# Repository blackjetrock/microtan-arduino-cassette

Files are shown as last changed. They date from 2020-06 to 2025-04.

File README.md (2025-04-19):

# microtan-arduino-cassette
Arduino based cassette system for Microtan computer

Uses Arduino Mega or Uno, depending on how much memory you need. Uno has 2K RAM mega has 8K. You can't use all of it for a buffer to store cassette information.

The connections to the cassette interface are not the external ones that attach to a tape recorder. They are instead pins 11 and 12 of connector B1 on the TANEX. This is logic level and removes the need for amplifiers and so on. Ground is also needed on B1.

The code runs only in fast mode. The data read from the Microtan is dumped to a buffer that can then go to an SD card.

SD card read isn't working yet.

When using the SAVE command the code displays data as it is received. The serial port on the Arduino runs at 115200 and there's enough time to send the bytes out of the port as the data is received.

Commands

clear:    Clears the memory buffer ready for a new SAVE.

display:  Displays the current contents of the buffer

savefile: Saves the buffer to a file on the attached SD card. The filename used is the embedded name in the data. 
          Data is curently saved in ASCII hex but binary is probably better as it can be directly sent back to the Microtan.

send:     Sends the data buffer back to the Microtan. There's a spurious byte at the start of the buffer that isn't sent back.

There are other commands used in development, I need to remove those or at least tidy them up.

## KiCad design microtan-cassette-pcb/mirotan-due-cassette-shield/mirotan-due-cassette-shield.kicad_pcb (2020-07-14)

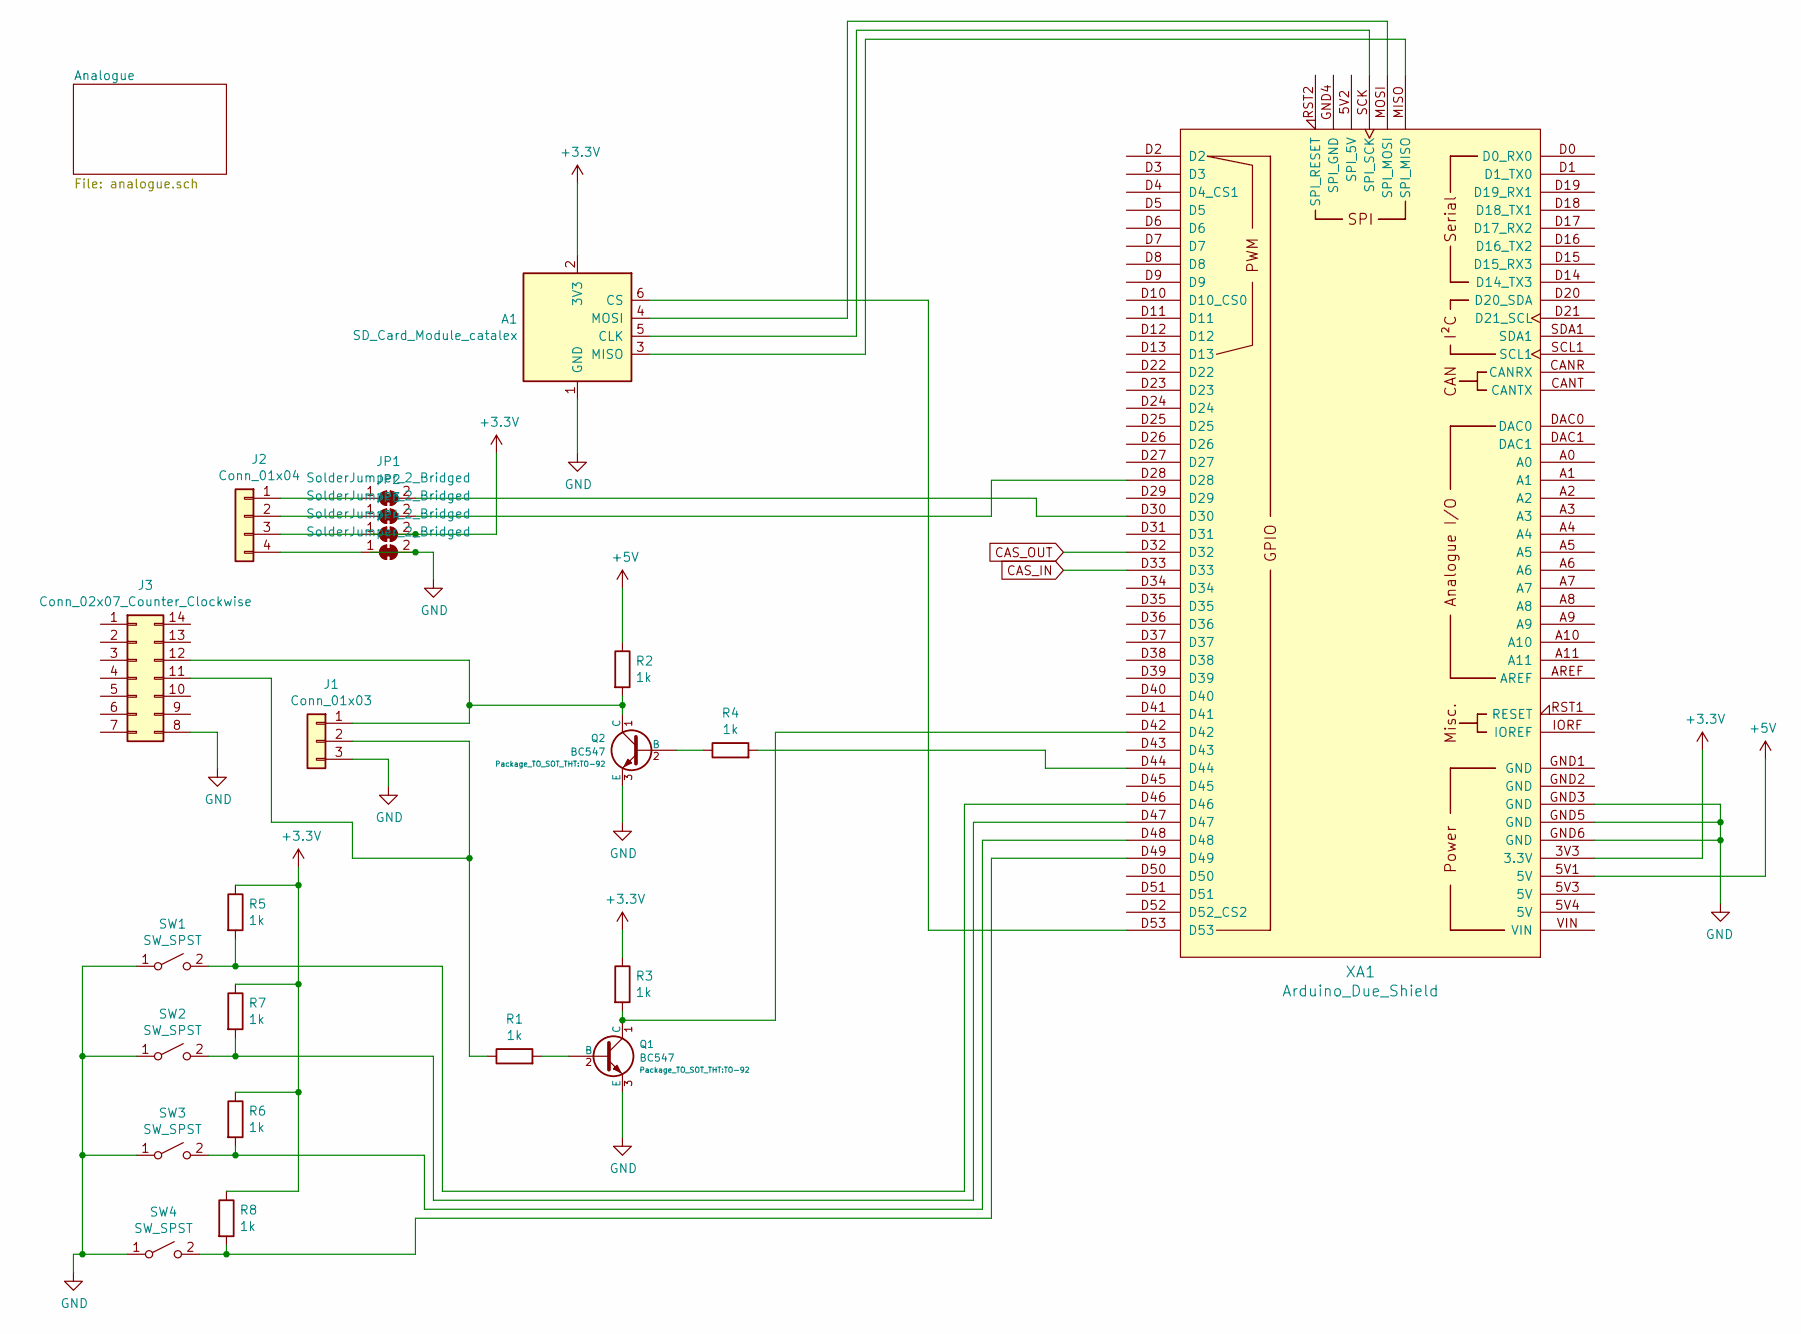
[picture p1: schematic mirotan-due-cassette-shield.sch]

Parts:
A1: SD_Card_Module_catalex; SD_Card_Module
J1: Conn_01x03; Molex_KK-254_AE-6410-03A_1x03_P2.54mm_Vertical
J2: Conn_01x04; Molex_KK-254_AE-6410-04A_1x04_P2.54mm_Vertical
J3: Conn_02x07_Counter_Clockwise; DIP-14_W7.62mm_Socket
JP1, JP2, JP3, JP4: SolderJumper_2_Bridged; SolderJumper-2_P1.3mm_Bridged2Bar_RoundedPad1.0x1.5mm
Q1, Q2: BC547; TO-92
R1, R2, R3, R4, R5, R6, R7, R8: 1k; R_Axial_DIN0207_L6.3mm_D2.5mm_P7.62mm_Horizontal
SW1, SW2, SW3, SW4: SW_SPST; SW_PUSH-12mm
XA1: Arduino_Due_Shield

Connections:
+3V3: A1.2 (3V3), JP3.2 (B), R3.1, R5.1, R6.1, R7.1, R8.1, XA1.3V3 (3.3V)
+5V: R2.1, XA1.5V1 (5V); also elsewhere on the board
CAS_IN: XA1.D33; also elsewhere on the board
CAS_OUT: XA1.D32; also elsewhere on the board
GND: A1.1 (GND), J1.3, J3.8, JP4.2 (B), Q1.3 (E), Q2.3 (E), SW1.1 (A), SW2.1 (A), SW3.1 (A), SW4.1 (A), XA1.GND3 (GND), XA1.GND5 (GND), XA1.GND6 (GND); also elsewhere on the board
unnamed: A1.3 (MISO), XA1.MISO (SPI_MISO)
unnamed: A1.4 (MOSI), XA1.MOSI (SPI_MOSI)
unnamed: A1.5 (CLK), XA1.SCK (SPI_SCK)
unnamed: A1.6 (CS), XA1.D53
unnamed: J1.1, J3.12, Q2.1 (C), R2.2
unnamed: J1.2, J3.11, R1.1
unnamed: J2.1, JP1.1 (A)
unnamed: J2.2, JP2.1 (A)
unnamed: J2.3, JP3.1 (A)
unnamed: J2.4, JP4.1 (A)
unnamed: JP1.2 (B), XA1.D30
unnamed: JP2.2 (B), XA1.D28
unnamed: Q1.1 (C), R3.2, XA1.D42
unnamed: Q1.2 (B), R1.2
unnamed: Q2.2 (B), R4.1
unnamed: R4.2, XA1.D44
unnamed: R5.2, SW1.2 (B), XA1.D46
unnamed: R6.2, SW3.2 (B), XA1.D48
unnamed: R7.2, SW2.2 (B), XA1.D47
unnamed: R8.2, SW4.2 (B), XA1.D49

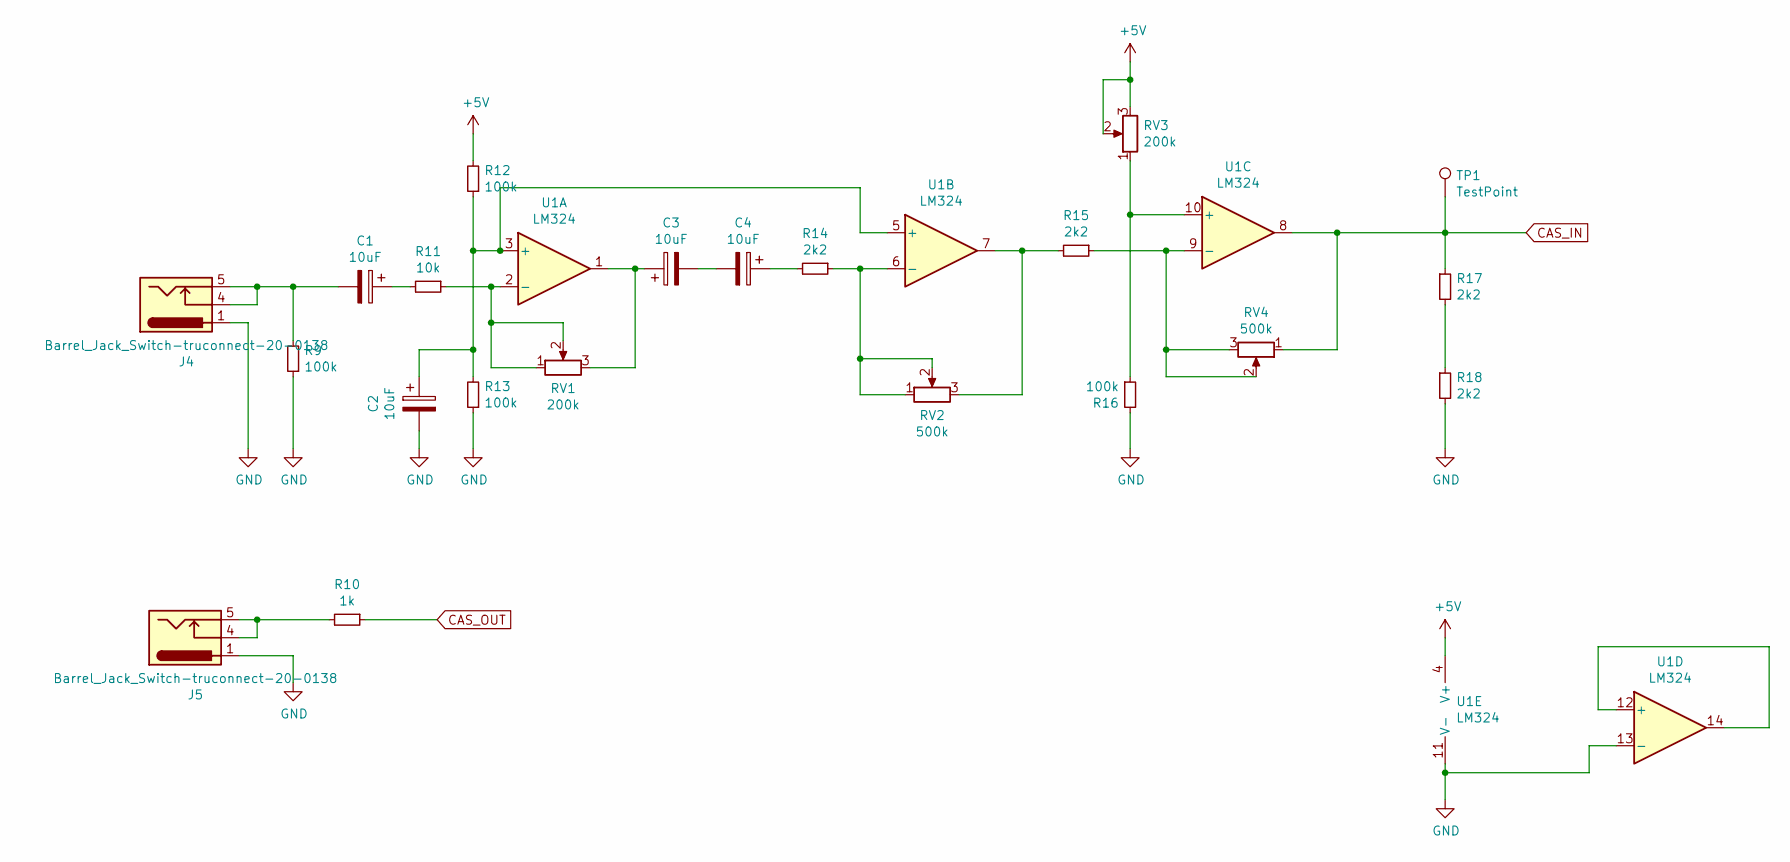
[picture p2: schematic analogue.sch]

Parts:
C1, C2, C3, C4: 10uF; CP_Radial_D5.0mm_P2.50mm
J4, J5: Barrel_Jack_Switch-truconnect-20-0138; truconnect-20-0138-mono-socket
R9, R12, R13, R16: 100k; R_Axial_DIN0207_L6.3mm_D2.5mm_P7.62mm_Horizontal
R10: 1k; R_Axial_DIN0207_L6.3mm_D2.5mm_P7.62mm_Horizontal
R11: 10k; R_Axial_DIN0207_L6.3mm_D2.5mm_P7.62mm_Horizontal
R14, R15, R17, R18: 2k2; R_Axial_DIN0207_L6.3mm_D2.5mm_P7.62mm_Horizontal
RV1, RV3: 200k; Potentiometer_Bourns_3296W_Vertical
RV2, RV4: 500k; Potentiometer_Bourns_3296W_Vertical
TP1: TestPoint; TestPoint_Loop_D1.80mm_Drill1.0mm_Beaded
U1: LM324; DIP-14_W7.62mm

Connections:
+5V: R12.2, RV3.2, RV3.3, U1.4 (V+); also elsewhere on the board
CAS_IN: R17.1, RV4.1, TP1.1, U1.8; also elsewhere on the board
CAS_OUT: R10.1; also elsewhere on the board
GND: C2.2, J4.1, J5.1, R9.1, R13.1, R16.2, R18.2, U1.11 (V-), U1.13 (-); also elsewhere on the board
unnamed: C1.1, R11.2
unnamed: C1.2, J4.4, J4.5, R9.2
unnamed: C2.1, R12.1, R13.2, U1.3 (+), U1.5 (+)
unnamed: C3.1, RV1.3, U1.1
unnamed: C3.2, C4.2
unnamed: C4.1, R14.2
unnamed: J5.4, J5.5, R10.2
unnamed: R11.1, RV1.1, RV1.2, U1.2 (-)
unnamed: R14.1, RV2.1, RV2.2, U1.6 (-)
unnamed: R15.1, RV4.2, RV4.3, U1.9 (-)
unnamed: R15.2, RV2.3, U1.7
unnamed: R16.1, RV3.1, U1.10 (+)
unnamed: R17.2, R18.1
unnamed: U1.12 (+), U1.14

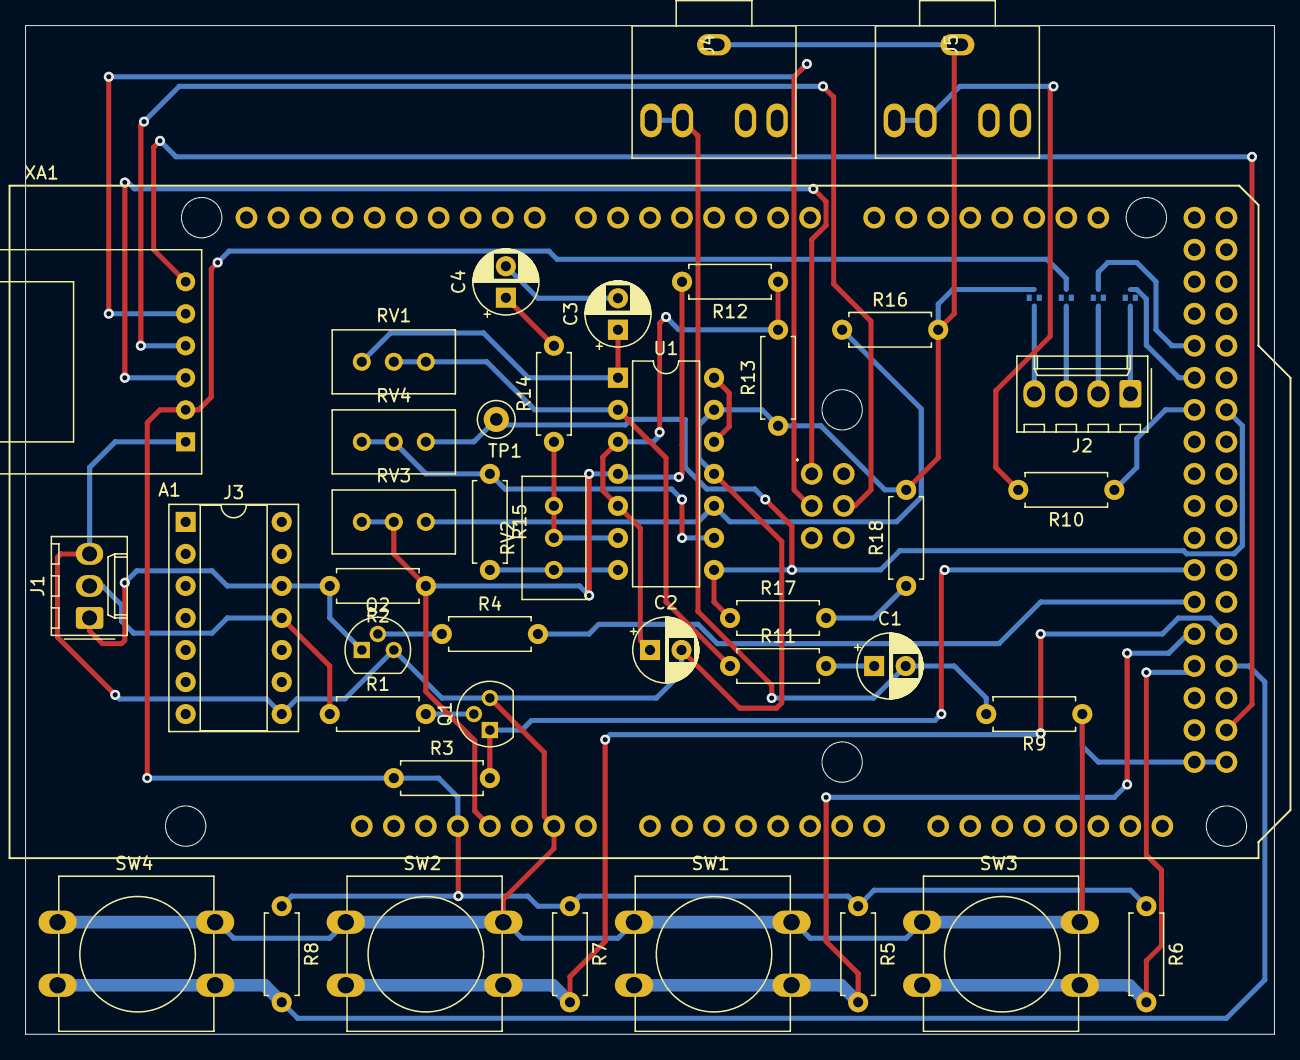
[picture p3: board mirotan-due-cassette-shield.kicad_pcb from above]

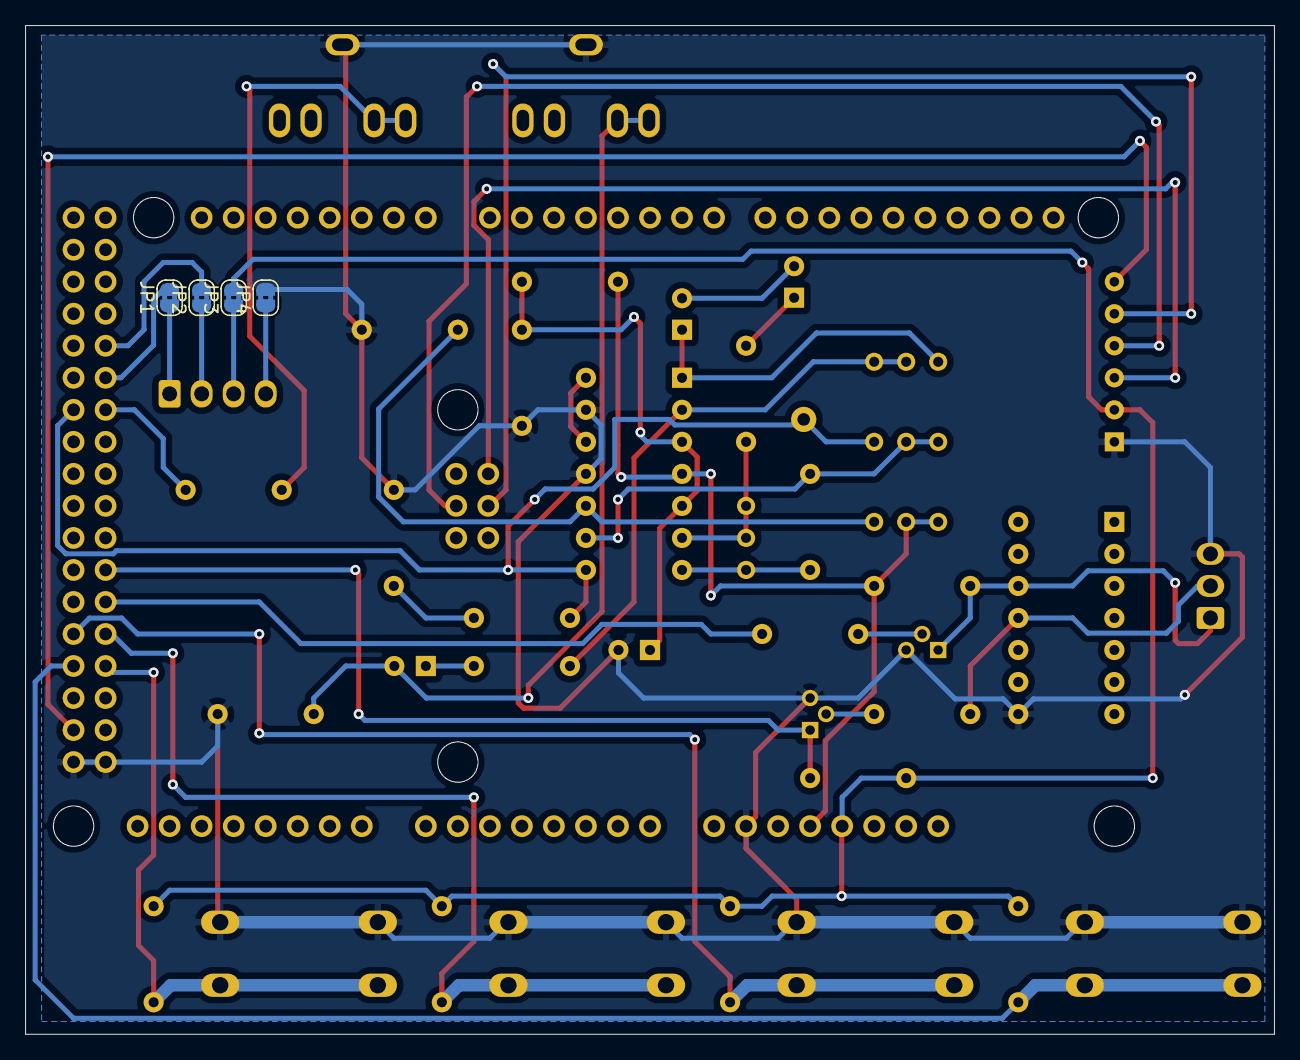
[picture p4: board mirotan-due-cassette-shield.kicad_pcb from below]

Board: 2 copper layers, 99.1 x 80.0 mm, 45 parts (4 on the bottom side), 39 nets.

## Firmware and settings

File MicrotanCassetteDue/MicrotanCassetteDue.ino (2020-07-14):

#include <SoftWire.h>

#include <SPI.h>
#include <SD.h>
#include "miniOled.h"

#define DEBUG 0

void cmd_help(String cmd);
  
// set up variables using the SD utility library functions:
Sd2Card card;
SdVolume volume;
SdFile root;

File myFile;

// Capture file
File dumpfile;


#define DEBUG_SERIAL 0
#define DIRECT_WRITE 0

#define BOARD_DUE 1
#define BOARD_MEGA 0

#if BOARD_DUE
const int micPin = 42;
const int statPin = 48;
const int dataPin = 49;
const int earPin = 44;
const int switchPin = 5;
const int MAX_BYTES = 40000;
const int chipSelect = 53;
const int button1Pin = 46;
const int button2Pin = 47;
const int button3Pin = 48;

#endif

#if BOARD_MEGA
const int micPin = 2;
const int statPin = 8;
const int dataPin = 9;
const int earPin = 3;
const int switchPin = 5;
const int MAX_BYTES = 5000;
const int chipSelect = 53;
const int button1Pin = 46;
const int button2Pin = 47;
const int button3Pin = 48;
#endif

typedef unsigned char BYTE;

typedef void (*FPTR)();
typedef void (*CMD_FPTR)(String cmd);

#define NUM_BUTTONS 3

// Debounce
#define MAX_BUT_COUNT 2

int but_pins[NUM_BUTTONS] = {button1Pin, button2Pin, button3Pin};

typedef struct _BUTTON
{
  int     count;
  boolean pressed;
  boolean last_pressed;   // For edge detection
  FPTR    event_fn;
} BUTTON;

BUTTON buttons[NUM_BUTTONS];

enum ELEMENT_TYPE
  {
    BUTTON_ELEMENT = 10,
    SUB_MENU,
    MENU_END,
  };

struct MENU_ELEMENT
{
  enum ELEMENT_TYPE type;
  char *text;
  void *submenu;
  void (*function)(struct MENU_ELEMENT *e);
};


struct MENU_ELEMENT *current_menu;
struct MENU_ELEMENT *last_menu;
struct MENU_ELEMENT *the_home_menu;
unsigned int menu_selection = 0;
unsigned int menu_size = 0;

#define MAX_LISTFILES 7
#define MAX_NAME 20

MENU_ELEMENT listfiles[MAX_LISTFILES];
int num_listfiles;
char names[MAX_LISTFILES][MAX_NAME];
char selected_file[MAX_NAME+1];
char current_file[MAX_NAME+1];

#define IF_2400 if(delta<500)
#define IF_1200 if(delta>=500)


void state_got2400()
{
}

// Start in this state
void state_start()
{
  int delta = 0;
  
  IF_2400
    {
      state_got2400();
    }
}

volatile int data_byte;
volatile int bit_count;
volatile int got_byte = 0;
volatile int state = 0;
volatile int data_bit = 2;
volatile int got_bit = 0;


enum
  {
    INIT = 0,
    RX_D0_1,
    RX_D0_2,
    RX_D0_3,
    RX_D1_1,
    RX_D1_2,
    RX_D1_3,
    RX_D1_4,
    RX_D1_5,
    RX_D1_6,
    RX_D1_7,
    RX_1,
    RX_0,
    BAD12,
    BAD24,
    BAD_START,
  };

#if 0

// Casio fx502p, original table
struct
{	
  FPTR entry_function;
  int goto_if_1200;
  int goto_if_2400;
  
} state_table[] =
  // decodes to a bit stream
  //                    1200          2400
  {
    {state_null,        RX_D0_1,       RX_D1_1},     //  INIT
    {state_null,        RX_D0_2,       RX_D1_1},       //  RX_D0_1
    {state_null,        RX_D0_3,       RX_D1_1},       //  RX_D0_2
    {state_null,        RX_0,          RX_D1_1},       //  RX_D0_3

    {state_null,        RX_D0_1,       RX_D1_2},     //  RX_D1_1
    {state_null,        RX_D0_1,       RX_D1_3},     //  RX_D1_2
    {state_null,        RX_D0_1,       RX_D1_4},     //  RX_D1_3
    {state_null,        RX_D0_1,       RX_D1_5},     //  RX_D1_4
    {state_null,        RX_D0_1,       RX_D1_6},     //  RX_D1_5
    {state_null,        RX_D0_1,       RX_D1_7},     //  RX_D1_6
    {state_null,        RX_D0_1,       RX_1},        //  RX_D1_7

    // We have a 1 or a 0 data bit
    {state_rx_1,        RX_D0_1,       RX_D1_1},         //  RX 1
    {state_rx_0,        RX_D0_1,       RX_D1_1},         //  RX 0
    
    {state_null,        BAD12,        BAD12},        //  7 BAD12
    {state_null,        BAD24,        BAD24},        //  7 BAD24
    {state_null,        BAD_START,    BAD_START},    //  7 BAD_START
  };

#else

// Microtan 65 table for FAST mode
struct
{	
  FPTR entry_function;
  int goto_if_1200;
  int goto_if_2400;
  
} state_table[] =
  // decodes to a bit stream
  //                    1200          2400
  {
    {state_null,        RX_0,          RX_1},           //  INIT
    {state_null,        RX_D0_2,       RX_D1_1},       //  RX_D0_1
    {state_null,        RX_D0_3,       RX_D1_1},       //  RX_D0_2
    {state_null,        RX_0,          RX_D1_1},       //  RX_D0_3

    {state_null,        RX_D0_1,       RX_D1_2},     //  RX_D1_1
    {state_null,        RX_D0_1,       RX_D1_3},     //  RX_D1_2
    {state_null,        RX_D0_1,       RX_D1_4},     //  RX_D1_3
    {state_null,        RX_D0_1,       RX_D1_5},     //  RX_D1_4
    {state_null,        RX_D0_1,       RX_D1_6},     //  RX_D1_5
    {state_null,        RX_D0_1,       RX_D1_7},     //  RX_D1_6
    {state_null,        RX_D0_1,       RX_1},        //  RX_D1_7

    // We have a 1 or a 0 data bit
    {state_rx_1,        INIT,         INIT},            //  RX 1
    {state_rx_0,        INIT,         INIT},           //  RX 0
    
    {state_null,        BAD12,        BAD12},        //  7 BAD12
    {state_null,        BAD24,        BAD24},        //  7 BAD24
    {state_null,        BAD_START,    BAD_START},    //  7 BAD_START
  };

#endif

void state_null()
{
}

// Start bit just received
void state_start_byte()
{
  data_byte = 0;
  bit_count = 0;
}

void state_rx_0()
{
  data_bit = 0;
  got_bit = 1;
}

void state_rx_1()
{
  data_bit = 1;
  got_bit = 1;
}

void xstate_rx_0()
{
  data_byte <<=1;
  bit_count++;
  if( bit_count == 8)
    {
      // Got a data byte
      got_byte =1;
      //      state = WAIT_CHECK;
    }

}

void xstate_rx_1()
{
  data_byte <<=1;
  data_byte++;
  bit_count++;
  if( bit_count == 8)
    {
      // Got a data byte
      got_byte =1;
      //      state = WAIT_CHECK;
    }
  
}

void state_check_ok()
{
}

void state_check_bad()
{
}


int last_micstate = 0, micstate = 0;
volatile long t, t2 = 0;
long delta = 0;
int ix = 0;

long mint = 100000;
long maxt = 0;
long quiet = 0;
long trans = 0;
volatile long hz2400=0, hz1200=0;

long count = 0;
long last = 0;

enum
  {
    BINIT = 0,
    BRX_H_1,
    BRX_START,
    BRX_D0_0,
    BRX_D1_0,
    BRX_D2_0,
    BRX_D3_0,
    BRX_D4_0,
    BRX_D5_0,
    BRX_D6_0,
    BRX_D7_0,
    BRX_D0_1,
    BRX_D1_1,
    BRX_D2_1,
    BRX_D3_1,
    BRX_D4_1,
    BRX_D5_1,
    BRX_D6_1,
    BRX_D7_1,
    BRX_PARITY_0,
    BRX_PARITY_1,
    BRX_DUMMY1,
    BRX_BYTEDONE,
  };

int byte_state = 0;
int databyte = 0;

void state_clrbyte()
{
  databyte=0;
}

// Microtan has inverted data so the data stored here is inverted
void state_databit1()
{
  databyte >>= 1;
}

void state_databit0()
{
  databyte >>= 1;
  databyte+=0x80;
}

int calcpar(int b)
{
  int i;
  int one_count = 0;
  for(i=0; i<8; i++)
    {
      one_count += ((b >> i) & 1);
    }

  return((one_count & 1));
}

void state_chkpar0()
{
  int par = calcpar(databyte);
  if( par == 0 )
    {
      // All ok
#if DEBUG_SERIAL      
      Serial.println("D");
      Serial.println(databyte,HEX);
#endif
    }
  else
    {
#if DEBUG_SERIAL
      Serial.println("E");
      Serial.println(databyte,HEX);
#endif
    }
}

void state_chkpar1()
{
  int par = calcpar(databyte);
  if( par == 1 )
    {
      // All ok
#if DEBUG_SERIAL
      Serial.println("D");
      Serial.println(databyte,HEX);
#endif
    }
  else
    {
#if DEBUG_SERIAL
      Serial.println("E");
      Serial.println(databyte,HEX);
#endif
    }
}

// How many bytes in the buffer. We have a default for testing without a Microtan
int bytecount = 24;

void state_init()
{
#if DEBUG_SERIAL  
  Serial.println("I");
#endif  
  
}

// Where the received data goes

char stored_bytes[MAX_BYTES] = "Test data example. 01234567890";


// Two versions of this, one that writes data to a buffer that you have to then write to
// a file, and a second that writes directly to the SD card

#if !DIRECT_WRITE

void state_bytedone()
{
  // There's a spurious character at the start, we don't want to store it at all
  if( bytecount >= 0 )
    {
      stored_bytes[bytecount] = databyte;
      
      Serial.print(databyte, HEX);
      Serial.print(" ");
      
      if( bytecount == 0 )
	{
	  if( databyte & 1 )
	    {
	      digitalWrite(LED_BUILTIN, HIGH);
	    }
	  else
	    {
	      digitalWrite(LED_BUILTIN, LOW);
	    }
	}
    }
  
  //  myFile.println(databyte, HEX);
  bytecount++;
  if( bytecount >= MAX_BYTES )
    {
      bytecount = MAX_BYTES;
    }
  
  if( (bytecount % 16) == 0 )
    {
      Serial.println("");
    }
}

#else

// This one writes dirctly to SD card
// A clear is needed to reset counters etc

int filename_i = 0;
char filename[9] = "";

void state_bytedone()
{
  // There's a spurious character at the start, we don't want to store it at all
  if( bytecount >= 0 )
    {
      if( bytecount == 0 )
	{
	  // Reset filename capture
	  filename_i = 0;
	}

      // We need to capture the filename
      if( (bytecount >=0) && (bytecount <=7) )
	{
	  filename[filename_i++] = databyte;
	}

      if( bytecount == 8 )
	{
	  Serial.println(filename);
	}
      
      // Write to file
      dumpfile.write(databyte);
      
      Serial.print(databyte, HEX);
      Serial.print(" ");
      
      if( bytecount == 0 )
	{
	  if( databyte & 1 )
	    {
	      digitalWrite(LED_BUILTIN, HIGH);
	    }
	  else
	    {
	      digitalWrite(LED_BUILTIN, LOW);
	    }
	}
    }
  
  //  myFile.println(databyte, HEX);
  bytecount++;
  if( bytecount >= MAX_BYTES )
    {
      bytecount = MAX_BYTES;
    }
  
  if( (bytecount % 16) == 0 )
    {
      Serial.println("");
    }
}

#endif


struct
{	
  FPTR entry_function;
  int goto_if_0;
  int goto_if_1;
  
} byte_state_table[] =
  // decodes to a bit stream
  //                    0                1
  {
    {state_init,        BINIT,          BRX_START},    //  BINIT       0
    {state_clrbyte,     BRX_START,      BRX_H_1},      //  BRX_H_1     1
    {state_clrbyte,     BRX_D0_0,       BRX_D0_1},     //  BRX_START   2
    {state_databit0,    BRX_D1_0,       BRX_D1_1},     //  BRX_D0_0    3
    {state_databit0,    BRX_D2_0,       BRX_D2_1},     //  BRX_D1_0    4
    {state_databit0,    BRX_D3_0,       BRX_D3_1},     //  BRX_D2_0    5
    {state_databit0,    BRX_D4_0,       BRX_D4_1},     //  BRX_D3_0    6
    {state_databit0,    BRX_D5_0,       BRX_D5_1},     //  BRX_D4_0    7
    {state_databit0,    BRX_D6_0,       BRX_D6_1},     //  BRX_D5_0    8
    {state_databit0,    BRX_D7_0,       BRX_D7_1},     //  BRX_D6_0    9
    {state_databit0,    BRX_PARITY_0,   BRX_PARITY_1}, //  BRX_D7_0   10
    {state_databit1,    BRX_D1_0,       BRX_D1_1},     //  BRX_D0_1   11
    {state_databit1,    BRX_D2_0,       BRX_D2_1},     //  BRX_D1_1   12
    {state_databit1,    BRX_D3_0,       BRX_D3_1},     //  BRX_D2_1   13
    {state_databit1,    BRX_D4_0,       BRX_D4_1},     //  BRX_D3_1   14
    {state_databit1,    BRX_D5_0,       BRX_D5_1},     //  BRX_D4_1   15
    {state_databit1,    BRX_D6_0,       BRX_D6_1},     //  BRX_D5_1   16
    {state_databit1,    BRX_D7_0,       BRX_D7_1},     //  BRX_D6_1   17
    {state_databit1,    BRX_PARITY_0,   BRX_PARITY_1}, //  BRX_D7_1   18
    {state_chkpar0,     BRX_DUMMY1,     BRX_DUMMY1},   //  BRX_PARITY_0  19
    {state_chkpar1,     BRX_DUMMY1,     BRX_DUMMY1},   //  BRX_PARITY_1  20
    {state_null,        BRX_BYTEDONE,   BRX_BYTEDONE}, //  BRX_DUMMY1    21
    {state_bytedone,    BINIT,          BINIT},        //  BRX_BYTEDONE  22

  };

// Sends a bit out of the ear port

// for fx502p
const int base_period=200;
//const int base_period=104;

void send_bit(int b)
{
  int i;

#if 0
  Serial.print(b);
#endif
  
  if( b )
    {
      // Send 1
      for(i=0;i<1;i++)
	{
	  digitalWrite(earPin, LOW);
	  delayMicroseconds(base_period*2);
	  digitalWrite(earPin, HIGH);
	  delayMicroseconds(base_period);
	}
    }
  else
    {
      // Send 0
      for(i=0;i<1;i++)
	{
	  digitalWrite(earPin, LOW);
	  delayMicroseconds(base_period);
	  digitalWrite(earPin, HIGH);
	  delayMicroseconds(base_period);
	}
    }
}

//
// Sends the data buffer back to the Microtan
//

void send_databytes()
{
  int i, b;
  int j;
  int databyte;
  int parity;
 
  Serial.println("Sending...");
  Oled.clearDisplay();
  Oled.printString("Sending...", 0,1);
  

  // Make ear pin an output while sending then input at all other times so
  // cassette inputs will still work

  pinMode(earPin,     OUTPUT);

  // Turn interrupts of as we want good timing for the data
  noInterrupts();
  
  // Send stored data back out
  // Header
  for(i=0; i<2400*5; i++)
    {
#if 0      
      digitalWrite(earPin, LOW);
      delayMicroseconds(base_period);
      digitalWrite(earPin, HIGH);
      delayMicroseconds(base_period);
#else
      send_bit(0);
#endif
      
    }
  
  // Now send data back
  for(b=0; b<bytecount; b++)
    {
      // Start bit
      send_bit(1);
      
      parity = 0;
      databyte = stored_bytes[b];
      
      // Send bits
      for(j=0; j<8; j++)
	{
	  if( !(databyte & 1) )
	    {
	      parity++;
	      send_bit(1);
	    }
	  else
	    {
	      send_bit(0);
	    }
	  databyte >>=1;
	}
      
      // Send parity
      if( (parity & 1) )
	{
	  send_bit(1);
	}
      else
	{
	  send_bit(0);
	}
      
      // Send two 0's as stop
      send_bit(0);
      send_bit(0);

      // Send extra delay after header as load seems to fail without this
      if( b == 11 )
	{
	  // 60ms of zeros
	  for(int z=0;z<300;z++)
	    {
	      send_bit(0);
	    }
	}
    }
  interrupts();

  pinMode(earPin,     INPUT);
    
  Serial.println("Sent.");
  Oled.printString("Sending...", 0,1);
  delay(2000);
  
  draw_menu(current_menu, true);

}

//
// Allow interaction with serial monitor
//

// Commands
int indx = 0;

void cmd_next(String cmd)
{
  indx++;
}

void cmd_prev(String cmd)
{
  indx--;
}

void cmd_index(String cmd)
{
  String arg;
  
  Serial.println("INDEX");
  arg = cmd.substring(1);
  Serial.println(arg);
  
  indx = arg.toInt();
}

// Modify the buffer
void cmd_modify(String cmd)
{
  String arg;
  
  Serial.println("MOD");
  arg = cmd.substring(1);

  if( indx <= MAX_BYTES )
    {
      stored_bytes[indx] = arg.toInt();
    }
}

#define DISPLAY_COLS 16

// Displays the file data, with offset and address (from start address stored in file data)

void cmd_display(String cmd)
{
  int i;
  int address = stored_bytes[10]*256+stored_bytes[11]-12;
  
  char ascii[DISPLAY_COLS+2];
  char c[2];
  char line[50];
  
  int ascii_i = 0;
  ascii[0] ='\0';
  
  Serial.print("Byte Count:");
  Serial.print(bytecount);
  Serial.print("  Index:");
  Serial.println(indx);

  for(i=0; i<bytecount; i++)
    {
      if( (i%DISPLAY_COLS)==0 )
	{
	  sprintf(line, "%s\n%04X %04X:", ascii, i, address); 	  
	  Serial.print(line);
	  ascii_i = 0;
	}

      sprintf(line, "%02X ", stored_bytes[i]);
      Serial.print(line);
      
      if( isprint(stored_bytes[i]) )
	{
	  sprintf(c, "%c", stored_bytes[i]);
	}
	else
	  {
	    c[0] ='.';
	  }
      ascii[ascii_i++] = c[0];
      ascii[ascii_i] = '\0';
      
      address++;
    }

  ascii[ascii_i++] = '\0';

  // Pad to the ascii position
  for(i=ascii_i-1; i<DISPLAY_COLS; i++)
    {
      Serial.print("   ");
    }
  
  Serial.print(ascii);
  Serial.print(" ");
  Serial.println("");
}

// Clear the buffer


void cmd_clear(String cmd)
{
  bytecount = -1;    // We reset to -1 so we drop the leading spurious character

#if DIRECT_WRITE
    SD.remove(filename);
    dumpfile = SD.open("dumpfile.bin", FILE_WRITE);
#endif
  
}


// Close the capture file
void cmd_close(String cmd)
{
  dumpfile.close();
}

void cmd_send(String cmd)
{
  send_databytes();
}

// Deletes a file
void cmd_deletefile(String cmd)
{
  String arg;
  
  arg = cmd.substring(strlen("delete "));

  Serial.print("Deleting file '");
  Serial.print(arg);
  Serial.println("'");
  
  SD.remove(arg);
}

// read the file with the given name into the buffer

void core_read(String arg, boolean oled_nserial)
{
  if( oled_nserial )
    {
      Oled.clearDisplay();
      Oled.printString("Reading file ", 0, 0);
      Oled.printString(arg.c_str(), 0, 1);
    }
  else
    {
      Serial.print("Reading file '");
      Serial.print(arg);
      Serial.println("'");
    }
  
  myFile = SD.open(arg);

  if (myFile)
    {
      // Read from the file and store it in the buffer
      bytecount = 0;
      
      while (myFile.available())
	{
	  stored_bytes[bytecount++] = myFile.read();
	  if( bytecount >= MAX_BYTES )
	    {
	      bytecount = MAX_BYTES;
	    }
	  
	}
      
      // close the file:
      myFile.close();

      if ( oled_nserial )
	{
	  Oled.printInt(bytecount, 0,4);
	  Oled.printString(" bytes read.");
	  delay(3000);
	}
      else
	{
	  Serial.print(bytecount);
	  Serial.println(" bytes read.");
	}
    }
  else
    {
      // if the file didn't open, print an error:
      if( oled_nserial )
	{
	  Oled.printString("Error opening", 0, 4);
	  Oled.printString(arg.c_str(), 0, 5);
	  
	}
      else
	{
	  Serial.print("Error opening ");
	  Serial.println(arg);
	}
    }
}

void cmd_readfile(String cmd)
{
  String arg;
  
  arg = cmd.substring(strlen("read "));

  core_read(arg, false);
}

void cmd_listfiles(String cmd)
{
  File dir;
  
  dir = SD.open("/");

  // return to the first file in the directory
  dir.rewindDirectory();
  
  while (true) {
    
    File entry =  dir.openNextFile();
    if (! entry) {
      // no more files
      break;
    }

    Serial.print(entry.name());

    if (entry.isDirectory())
      {
	Serial.println("/");
      }
    else
      {
	// files have sizes, directories do not
	Serial.print("\t\t");
	Serial.println(entry.size(), DEC);
      }
    entry.close();
  }

  dir.close();
}

void cmd_initsd(String cmd)
{
  if (!SD.begin(53)) {
    Serial.println("SD Card initialisation failed!");
  }
  else
    {
      Serial.println("SD card initialised.");
    }

}


// Writes the buffer to a file.
// Deletes any file that exists with the same name so that the resulting
// file is the same size as the buffer


void core_writefile(boolean oled_nserial)
{
  char filename[20] = "U___.txt";
  int i;
  
  // Get the filename from the data, we can't allow spaces in filenames
  sprintf(filename, "%c%c%c%c%c%c%c%c",
	  (stored_bytes[0]==' ')?'_':stored_bytes[0],
	  (stored_bytes[1]==' ')?'_':stored_bytes[1],
	  (stored_bytes[2]==' ')?'_':stored_bytes[2],
	  (stored_bytes[3]==' ')?'_':stored_bytes[3],
	  (stored_bytes[4]==' ')?'_':stored_bytes[4],
	  (stored_bytes[5]==' ')?'_':stored_bytes[5],
	  (stored_bytes[6]==' ')?'_':stored_bytes[6],
	  (stored_bytes[7]==' ')?'_':stored_bytes[7]
	  );

  if( oled_nserial )
    {
      Oled.clearDisplay();
      Oled.printString("", 0,0);
      Oled.printString("Writing ");
      Oled.printInt(bytecount);
      Oled.printString(" bytes to");
      Oled.printString("'", 0, 1);
      Oled.printString(filename);
      Oled.printString("'");
    }
  else
    {
      Serial.println("");
      Serial.print("Writing ");
      Serial.print(bytecount);
      Serial.print(" bytes to '");
      Serial.print(filename);
      Serial.print("'");
      Serial.println("");
    }
  
  // Delete so we have no extra data if the file is currently larger than the buffer
  SD.remove(filename);
  
  // Open file for writing
  myFile = SD.open(filename, FILE_WRITE);

  if( myFile )
    {
      // Write data
      for(i=0; i<bytecount; i++)
	{
	  myFile.write(stored_bytes[i]);
	}
      
      myFile.close();

      if( oled_nserial )
	{
	  Oled.setCursorXY(0,3);
	  Oled.printInt(bytecount);
	  Oled.printString(" bytes written");
	}
      else
	{
	  Serial.print(bytecount);
	  Serial.println(" bytes written");
	}
    }
  else
    {
      if(oled_nserial)
	{
	  Oled.printString("Could not open file", 0, 5);

	}
      else
	{
	  Serial.println("Could not open file");
	}
    }

  if( oled_nserial )
    {
      delay(2000);
    }
}

void cmd_writefile(String cmd)
{
  core_writefile(false);
}

const int NUM_CMDS = 14;
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
void loop()
{

  update_buttons();
  run_monitor();
  
  if( digitalRead(switchPin),0 )
    {
      // Send data in buffer back
      send_databytes();      
    }
  
  if( got_bit )
    {
      got_bit = 0;
      
#if 0
      Serial.print(data_bit);

      count++;
      if ((count % 32)==0 )
	{
	  Serial.println("");
	}
#endif
      
      // Use a state machine to decode frames into byte codes
      if ( data_bit == 0 )
	{
	  // Move to next state
	  byte_state = byte_state_table[byte_state].goto_if_0;
	  
	  // Execute entry function
	  (*byte_state_table[byte_state].entry_function)();
	}
      else
	{
	  // Move to next state
	  byte_state = byte_state_table[byte_state].goto_if_1;
	  
	  // Execute entry function
	  (*byte_state_table[byte_state].entry_function)();
	}

      #if 0
      if( byte_state != BINIT )
	{
	  Oled.printString("Rx", 12,7);
	}
      else
	{
	  Oled.printString("  ", 12,7);
	}
      #endif
      
#if 0
      Serial.print(":");
      Serial.print(byte_state);
      Serial.println(":");
#endif 
      
      //      Serial.print(" ");
      //Serial.print(state);
      //Serial.print(":");
      
      if( millis() - last > 2000,0 )
	{
	  Serial.println("");
	  Serial.print(byte_state);
	  Serial.println("");
	  
	  last = millis();
	}
    }
}

// 
// This is called when a falling edge is detected on the input pin
void lowISR()
{
  digitalWrite(statPin, HIGH);
  t = micros();
  delta = t - t2;
  t2 = t;
    if ( delta > 500 )
      //    if ( delta > (3*base_period) )
    {
      hz1200++;
      digitalWrite(dataPin, HIGH);

      // Got a 1 bit
      data_bit = 1;
      got_bit = 1;

#if 0      
      // Move to next state
      state = state_table[state].goto_if_1200;

      // Execute entry function
      (*state_table[state].entry_function)();
#endif      
    }
  else 
    {
      hz2400++;
      digitalWrite(dataPin, LOW);
      data_bit = 0;
      got_bit = 1;

#if 0      
      // Move to next state
      state = state_table[state].goto_if_2400;

      // Execute entry function
      (*state_table[state].entry_function)();
#endif      
    }  
  digitalWrite(statPin, LOW);

}

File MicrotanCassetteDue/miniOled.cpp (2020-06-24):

#include <LiquidCrystal.h>

/*
V 0.4.0  miniOled.cpp

A VERY BASIC oled SSD1306 (0.96" I2C) library, compatible with SoftWire I2C library.
Designed initially to fit on STM32F030F4P6 board (16K flash, 48 MHz):
       for software I2C able to have custom pin selection
       for small flash memory footprint

1. Text. (Very) small characters.  Optional double width. Variable chr-spacing.
      page mode: always in one of 8 fixed horizontal lines ("pages" of SSD1306)
      horizontal mode: streaming over many lines (no interline spacing control).
2. Also big font 18x24 (inside 24x32) numbers 0-9 only, plus " "   "-"   "."   "/"  and  ":"
      still aligned to start on one of the 8 pages/lines.
3. <hr> horizontal line.
4. Load bitmap image.

I2C pins (software) configurable.

I2C output is unbuffered, one byte transfer at a time. Slow.
Derived by substantial hacking (down) of following:
   https://github.com/mistertwo/ozoled-oled-display-096-i2c-driver-library     2014/2015 

You need to download & install two other-party libraries
https://www.arduinolibraries.info/libraries/soft-wire   The 2.0.0 version of SoftWire
https://github.com/stevemarple/AsyncDelay   The AsyncDelay library, used by SoftWire
*/

#include "miniOled.h"
#define SOFTWIRE
// define SOFTWIRE, and software library SoftWire will be used, with choice of pins
// undefine SOFTWIRE, and native Wire on sda PA10  scl PA9   will apply


#ifdef SOFTWIRE
	#include <SoftWire.h>
	SoftWire Wire(30, 28);  // default gpio (SoftWire needs a default)
#else
	#include <Wire.h>
#endif

// 6x8 Font ASCII 32 - 127 Implemented

const byte BasicFont[][5]  = {   // 5x8 in a 6x8 space.
	{0x00,0x00,0x00,0x00,0x00},
	{0x00,0x5F,0x00,0x00,0x00},
	{0x00,0x07,0x00,0x07,0x00},
	{0x14,0x7F,0x14,0x7F,0x14},
	{0x24,0x2A,0x7F,0x2A,0x12},
	{0x23,0x13,0x08,0x64,0x62},
	{0x36,0x49,0x55,0x22,0x50},
	{0x00,0x05,0x03,0x00,0x00},
	{0x1C,0x22,0x41,0x00,0x00},
	{0x41,0x22,0x1C,0x00,0x00},
	{0x08,0x2A,0x1C,0x2A,0x08},
	{0x08,0x08,0x3E,0x08,0x08},
	{0xA0,0x60,0x00,0x00,0x00},
	{0x08,0x08,0x08,0x08,0x08},
	{0x60,0x60,0x00,0x00,0x00},
	{0x20,0x10,0x08,0x04,0x02},
	{0x3E,0x51,0x49,0x45,0x3E},
	{0x00,0x42,0x7F,0x40,0x00},
	{0x62,0x51,0x49,0x49,0x46},
	{0x22,0x41,0x49,0x49,0x36},
	{0x18,0x14,0x12,0x7F,0x10},
	{0x27,0x45,0x45,0x45,0x39},
	{0x3C,0x4A,0x49,0x49,0x30},
	{0x01,0x71,0x09,0x05,0x03},
	{0x36,0x49,0x49,0x49,0x36},
	{0x06,0x49,0x49,0x29,0x1E},
	{0x00,0x36,0x36,0x00,0x00},
	{0x00,0xAC,0x6C,0x00,0x00},
	{0x08,0x14,0x22,0x41,0x00},
	{0x14,0x14,0x14,0x14,0x14},
	{0x41,0x22,0x14,0x08,0x00},
	{0x02,0x01,0x51,0x09,0x06},
	{0x32,0x49,0x79,0x41,0x3E},
	{0x7E,0x09,0x09,0x09,0x7E},
	{0x7F,0x49,0x49,0x49,0x36},
	{0x3E,0x41,0x41,0x41,0x22},
	{0x7F,0x41,0x41,0x22,0x1C},
	{0x7F,0x49,0x49,0x49,0x41},
	{0x7F,0x09,0x09,0x09,0x01},
	{0x3E,0x41,0x41,0x51,0x72},
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
};


// Big numbers font, from [  - . / 0 1 2 3 4 5 6 7 8 9 : ] - 72 bytes each.
const byte hugeFont [][72] = {   // 18x24 inside a 24x32 cell.
{0x00, 0x00, 0x00, 0x00, 0x00, 0x00, 0x00, 0x00, 0x00, 0x00, 0x00, 0x00,
	 0x00, 0x00, 0x00, 0x00, 0x00, 0x00, 0x00, 0x00, 0x00, 0x00, 0x00,
	  0x00, 0x00, 0x00, 0x00, 0x00, 0x00, 0x00, 0x00, 0x00, 0x00, 0x00,
	   0x00, 0x00, 0x0f, 0x0f, 0x0f, 0x0f, 0x0f, 0x0f, 0x0f, 0x0f, 0x0f,
	    0x0f, 0x0f, 0x0f, 0x0f, 0x0f, 0x0f, 0x0f, 0x00, 0x00, 0x00, 0x00,
	     0x00, 0x00, 0x00, 0x00, 0x00, 0x00, 0x00, 0x00, 0x00, 0x00, 0x00,
	      0x00, 0x00, 0x00, 0x00, 0x00}, // - minus

{0x00, 0x00, 0x00, 0x00, 0x00, 0x00, 0x00, 0x00, 0x00, 0x00, 0x00, 0x00,
	 0x00, 0x00, 0x00, 0x00, 0x00, 0x00, 0x00, 0x00, 0x00, 0x00, 0x00,
	  0x00, 0x00, 0x00, 0x00, 0x00, 0x00, 0x00, 0x00, 0x00, 0x00, 0x00,
	   0x00, 0x00, 0x00, 0x00, 0x00, 0x00, 0x00, 0x00, 0x00, 0x00, 0x00,
	    0x00, 0x00, 0x00, 0x00, 0x00, 0x00, 0x00, 0x00, 0x00, 0x00, 0x00,
	     0x00, 0x00, 0x00, 0x00, 0x00, 0x00, 0x00, 0x0f, 0x0f, 0x0f, 0x0f,
	      0x0f, 0x00, 0x00, 0x00, 0x00}, // dot

{0x00, 0x00, 0x00, 0x00, 0x00, 0x00, 0x00, 0x00, 0x00, 0x00, 0x00, 0x80,
	 0xE0, 0xF0, 0xF0, 0x70, 0x10, 0x00, 0x00, 0x00, 0x00, 0x00, 0x00,
	  0x00, 0x80, 0xE0, 0xF0, 0xFC, 0x7F, 0x3F, 0x0F, 0x03, 0x01, 0x00,
	   0x00, 0x00, 0x00, 0x00, 0xC0, 0xF0, 0xF8, 0xFE, 0x3F, 0x1F, 0x07,
	    0x01, 0x00, 0x00, 0x00, 0x00, 0x00, 0x00, 0x00, 0x00, 0x0C, 0x0F,
	     0x0F, 0x0F, 0x03, 0x00, 0x00, 0x00, 0x00, 0x00, 0x00, 0x00, 0x00,
	      0x00, 0x00, 0x00, 0x00, 0x00}, // slash /

{0xC0, 0xE0, 0xF0, 0xF0, 0xF0, 0xF0, 0xF0, 0xF0, 0xF0, 0xF0, 0xF0, 0xF0,
	 0xF0, 0xF0, 0xF0, 0xF0, 0xE0, 0xC0, 0xFF, 0xFF, 0xFF, 0xFF, 0x01,
	  0x00, 0x00, 0x00, 0x00, 0x00, 0x00, 0x00, 0x00, 0x01, 0xFF, 0xFF,
	   0xFF, 0xFF, 0xFF, 0xFF, 0xFF, 0xFF, 0x80, 0x00, 0x00, 0x00, 0x00,
	    0x00, 0x00, 0x00, 0x00, 0x80, 0xFF, 0xFF, 0xFF, 0xFF, 0x03, 0x07,
	     0x0F, 0x0F, 0x0F, 0x0F, 0x0F, 0x0F, 0x0F, 0x0F, 0x0F, 0x0F, 0x0F,
	      0x0F, 0x0F, 0x0F, 0x07, 0x03}, // 0

{0x00, 0x00, 0x00, 0x00, 0x00, 0x00, 0x00, 0x00, 0x00, 0x00, 0x00, 0xE0,
	 0xF0, 0xF0, 0xE0, 0x00, 0x00, 0x00, 0x00, 0x00, 0x00, 0x00, 0x00,
	  0x00, 0x00, 0x00, 0x00, 0x00, 0x00, 0xFF, 0xFF, 0xFF, 0xFF, 0x00,
	   0x00, 0x00, 0x00, 0x00, 0x00, 0x00, 0x00, 0x00, 0x00, 0x00, 0x00,
	    0x00, 0x00, 0xFF, 0xFF, 0xFF, 0xFF, 0x00, 0x00, 0x00, 0x00, 0x00,
	     0x00, 0x00, 0x00, 0x00, 0x00, 0x00, 0x00, 0x00, 0x00, 0x03, 0x07,
	      0x07, 0x03, 0x00, 0x00, 0x00},  // 1

{0xE0, 0xF0, 0xF0, 0xF0, 0xF0, 0xF0, 0xF0, 0xF0, 0xF0, 0xF0, 0xF0, 0xF0,
	 0xF0, 0xF0, 0xF0, 0xF0, 0xE0, 0x00, 0x81, 0xC1, 0xC0, 0xC0, 0xC0,
	  0xC0, 0xC0, 0xC0, 0xC0, 0xC0, 0xC0, 0xC0, 0xE1, 0xFF, 0xFF, 0xFF,
	   0xFF, 0x00, 0xFF, 0xFF, 0xFF, 0xFF, 0x87, 0x03, 0x03, 0x03, 0x03,
	    0x03, 0x03, 0x03, 0x03, 0x03, 0x03, 0x83, 0x81, 0x00, 0x07, 0x0F,
	     0x0F, 0x0F, 0x0F, 0x0F, 0x0F, 0x0F, 0x0F, 0x0F, 0x0F, 0x0F, 0x0F,
	      0x0F, 0x0F, 0x0F, 0x07, 0x00}, // 2

{0xE0, 0xF0, 0xF0, 0xF0, 0xF0, 0xF0, 0xF0, 0xF0, 0xF0, 0xF0, 0xF0, 0xF0,
	 0xF0, 0xF0, 0xF0, 0xF0, 0xE0, 0x00, 0x81, 0xC1, 0xC0, 0xC0, 0xC0,
	  0xC0, 0xC0, 0xC0, 0xC0, 0xC0, 0xC0, 0xC0, 0xE1, 0xFF, 0xFF, 0xFF,
	   0x7F, 0x00, 0x81, 0x83, 0x03, 0x03, 0x03, 0x03, 0x03, 0x03, 0x03,
	    0x03, 0x03, 0x03, 0x87, 0xFF, 0xFF, 0xFF, 0xFE, 0x00, 0x07, 0x0F,
	     0x0F, 0x0F, 0x0F, 0x0F, 0x0F, 0x0F, 0x0F, 0x0F, 0x0F, 0x0F, 0x0F,
	      0x0F, 0x0F, 0x0F, 0x07, 0x00},  // 3

{0xE0, 0xF0, 0xF0, 0xF0, 0x30, 0x00, 0x00, 0x00, 0x00, 0x00, 0x00, 0x00,
	 0x30, 0xF0, 0xF0, 0xF0, 0xE0, 0x00, 0xFF, 0xFF, 0xFF, 0xFF, 0xE0,
	  0xC0, 0xC0, 0xC0, 0xC0, 0xC0, 0xC0, 0xC0, 0xE0, 0xFF, 0xFF, 0xFF,
	   0xFF, 0x00, 0x01, 0x03, 0x03, 0x03, 0x03, 0x03, 0x03, 0x03, 0x03,
	    0x03, 0x03, 0x03, 0x07, 0xFF, 0xFF, 0xFF, 0xFF, 0x00, 0x00, 0x00,
	     0x00, 0x00, 0x00, 0x00, 0x00, 0x00, 0x00, 0x00, 0x00, 0x00, 0x0C,
	      0x0F, 0x0F, 0x0F, 0x07, 0x00},  // 4
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

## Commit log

2020-06-18 Added more file handling ommands. Read file added. Fixed listfiles problem.
    [MicrotanCassette.ino]
2020-06-18 Added remove file command. Shortened commands for quicker entry.
    [MicrotanCassette.ino]
2020-06-18 Fixed bug on receive.
    [MicrotanCassette.ino]
2020-06-18 Fixed problem with delay after header
    [MicrotanCassette.ino]
2020-06-21 Added PCB for mega on bus and cassette Updates to sketch
    [microtan-cassette-pcb-B_Cu.gbr, microtan-cassette-pcb-B_Mask.gbr, microtan-cassette-pcb-B_Paste.gbr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]
2020-06-23 Added changes to cassette and sketh
    [mirotan-due-cassette-shield-B_Cu.gbr, mirotan-due-cassette-shield-B_Mask.gbr, mirotan-due-cassette-shield-B_Paste.gbr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]
2020-06-24 Added Due version with switches and OLED display
2020-06-26 Updated shematic to fix problems found on PCB. Code has more OLED stuff.
    [mirotan-due-cassette-shield.sch]
2020-07-03 First fab files.
    [analogue.sch, mirotan-due-cassette-shield.kicad_pcb, mirotan-due-cassette-shield.sch]
2020-07-14 Sketch updates
    [mirotan-due-cassette-shield.kicad_pcb]
